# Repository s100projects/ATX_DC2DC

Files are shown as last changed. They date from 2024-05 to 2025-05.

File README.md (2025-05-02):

# ATX_DC2DC 
## Project Purpose and Goal ##
<b>The ATX DC2DC power supply board uses a 550W or greater ATX PC power supply (PSU) to generate common S-100 Bus voltages for S-100 computers and floppy disk drives.</b>

<b>Table of Contents:</b>
- [Project Overview](#project-overview)
  - [ATX DC2DC Board Image](#atx-dc2dc-board-image)
  - [ATX DC2DC Board Features](#atx-dc2dc-board-features)
  - [S-100 Voltage Outputs and Currents](#s-100-voltage-outputs-and-currents)
  - [ATX PSU Requirements](#atx-psu-requirements)
  - [ATX DC2DC Jumper Assignments](#atx-dc2dc-jumper-assignments)
- [ATX DC2DC Thermal and Current Limits](#atx-dc2dc-thermal-and-current-limits)
  - [7.5V or 8V Current and Thermal Limits](#7.5v-or-8v-current-and-thermal-limits)
  - [24V Current and Thermal Limits](#24v-current-and-thermal-limits)
  - [16V Current and Thermal Limits](#16v-current-and-thermal-limits)
  - [Fan Requirements above 70% Loading](#fan-requirements-above-70%-loading)
- [Installation and Wiring Requirements](#installation-and-wiring-requirements)
  - [ATX DC2DC Dimensions and Connector Locations](#atx-dc2dc-dimensions-and-connector-locations)
  - [Connector Pinout Tables](#connector-pinout-tables)
    - [J1: ATX Main Power Connector](#j1-atx-main-power-connector)
    - [J3: ATX CPU Power Connector](#j3-atx-cpu-power-connector)
    - [J5: ATX PCIE Power Connector](#j5-atx-pcie-power-connector)
    - [J13-14: 8in. Disk DC Power Connectors](#j13-14-8in-disk-dc-power-connectors)
    - [J15: S-100 Bus Power Output Connector](#j15-s-100-bus-power-output-connector)
    - [J16: Voltage/Current Monitor Connector](#j16-voltagecurrent-monitor-connector)
    - [J17: Control/Status Connector](#j17-controlstatus-connector)
    - [J22: FAN Control Connector](#j22-fan-control-connector)
    - [J23-26: PC FAN Connectors](#j23-26-pc-fan-connectors)

## Project Overview ##

The ATX DC2DC board was implemented as a 5.5" x 3.4" PCB to match the side profile of the common ATX power supply case to allow for using a 3D printed base-plate with double-sided tape to mount the ATX DCDC to the ATX PSU.

### ATX DC2DC Board Image ###

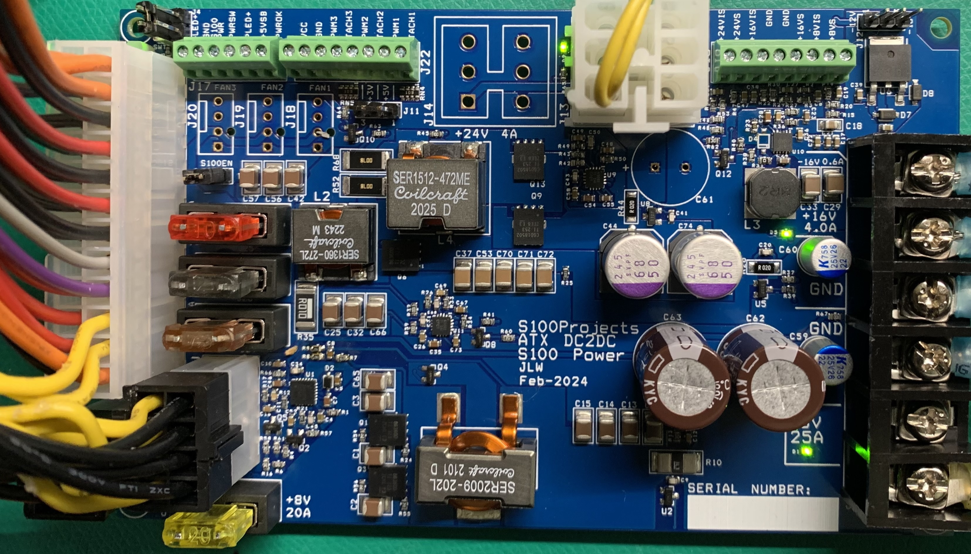
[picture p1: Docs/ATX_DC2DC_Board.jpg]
picture alt T35_FPGA_Module


### ATX DC2DC Board Features ###
The ATX DC2DC Board replaces several discrete power supply setups using efficient switching regulator power sections (+7.5V or +8V, +/-16V, and +24) and a readily available ATX PSU of 550 Watts or greater (See <b>ATX PSU Requirements</b> below).

<b>Current Features:</b>
  - Uses ATX Power Connectors (24-pin, 8-pin and 6-pin)
  - Supports common S-100 Voltages
  - Supports common 8" Disk Drive Voltages
  - Three 3/4-pin 12V PC Fan Connectors (with Tach and PWM off-board connections)
  - Microprocessor level (0 to 3.3V) voltage and current monitors for S-100 voltages
  - Over-current and over-temperature shutdown protection
  - Input fuses for each power supply section

### S-100 Voltage Outputs and Currents ###

  | <b>S-100 Output</b>   | <b>Function</b>                       | <b>Default Fuse Values</b>      |
  |----------------|--------------------------------|-----------------------|
  | <b>+7.5V</b> @ 25.0A   | Main Logic Supply on S-100 Bus | <b>~16.4A</b> (20.0A Fuse)   |
  |     - or -          |                                |                              |
  | <b>+8.0V</b> @ 22.0A   | Main Logic Supply on S-100 Bus | <b>~16.4A</b> (20.0A Fuse)   |
  | <b>+16V</b> @ 4.0A     | Logic/Shifter/Analog Supply    | <b>~5.7A</b>   (7.5A Fuse)   |
  | <b>-16V</b> @ 0.5A     | Level Shifter/Analog Supply    | <b>~0.8A</b>   (2.0A Fuse)   |
  | <b>+24V</b> @ 4.0A     | 8in. Floppy Drive Supply       | <b>~8.8A</b>  (10.0A Fuse)   |
  | <b>-5V</b> @ 0.3/0.5A\* | 8in. Floppy Drive Supply       | <b>Int. Limited to 0.5A</b>  |
  | <b>+5V</b> \*\*          | 8in. Floppy Drive Supply       | <b>Limited by ATX PSU</b>    |

\* = 0.3A when -5V Regulator is supplied by -16V Switcher.  
\* = 0.5A when -5V Regulator is supplied by -12V from ATX PSU.  
\*\* = Limited by ATX PSU.

Since not all ATX PSU's supply a -12V voltage (used by the on-board -5V regulator for the 8-in. Floppy Drive Power Connectors), a jumper is provided to optionally supply this -5V regulator from the -16V supply that the ATX DC2DC generates.  Due to dissipation reasons, the current output of the -5V regulator is reduced to 0.3A when driven from the -16V supply.

### ATX PSU Requirements ###

The main determination of which ATX PSU are acceptable are driven by the 12V load of the ATX DC2DC itself and the maximum load present on its outputs.  If you will be using the ATX DC2DC Board at its maximum load limits (as shown above) then you will need at least <b>32 amps</b> at 12V.  However, additional 12V loads such as Fans, Hard-Drives, LEDs, et cetera, will raise this requirement.  As a general rule, it is advised to add 5% or 10% margin to the current requirements to account for unanticipated loads or losses. 

### ATX DC2DC Jumper Assignments ###

  | <b>Jumper Number</b>  | <b>Description</b>                    | <b>Default Setting/Voltages</b> |
  |----------------|--------------------------------|-----------------------|
  | <b>J1  - 24-Pins</b>  | ATX Main Power Cable           | +3.3V, +5.0V, +12V, -12V                |
  | <b>J2  - 2-Pins</b>    | ATX Power Switch Connection    | Short pins for ATX PSU On               |
  | <b>J3  - 8-Pins</b>    | ATX 12V CPU Power Cable        | +12V when ATX PSU is On                 |
  | <b>J4  - 3-Pins</b>    | ATX Power LED Connection       | Pin 1 - Anode, 3 - Cathode              |
  | <b>J5  - 6-Pins</b>    | ATX 12V PCIE Power Cable       | +12V when ATX PSU is On                 |
  | <b>J10 - 2-Pins</b>    | S-100 Power Enable\*            | Power Enabled when shorted              |
  | <b>J11 - 3-Pins</b>    | Fan VCC Select - (for PWM)     | 1-2=5V, 2-3=3.3V                        |
  | <b>J12 - 3-Pins</b>    | -5V In Select (-12/-16)        | 1-2=-12V, 2-3=-16V                      |
  | <b>J13/14 - 6-Pins</b> | 8-in Drive Power Sockets       | 2/3/6=GND, 1=+24V, 4=-5V, 5=5V          |
  | <b>J15 - 6-Pins</b>    | S-100 Bus Voltage Outputs      | 1/2=+7.5V, 3/4=GND, 5=+16V, -16V        |
  | <b>J16 - 8-Pins</b>    | Voltage/Current Monitor Output | (See V/I Monitor Pinout)                |
  | <b>J17 - 6-Pins</b>    | Control/Status Port            | (See Control/Status Port Pinout)        |
  | <b>J18-20 - 4-Pins</b> | PC Fan Connections             | 1=GND, 2=+12V, 3=TACH, 4=PWM            |
  | <b>J22 - 8-Pins</b>    | Fan Control Connector          | (See Fan Control Connector Pinout)      |
  | <b>J23-26 - 2-Pins</b> | Power Supply Fuses             | J23=+7.5V, J24=+16V, J25=+24V, J26=-16V |
  
## ATX DC2DC Thermal and Current Limits ##

As shown above, the ATX DC2DC S-100 Power Supply Board can provide >350W of S-100 voltages, typically at 95%+ efficiency.

Even at those efficiency levels though, you will still have close to 18-watts of heat dissipation at full load.  The board can dissipate, with natural convection (under 25C ambient conditions), up to approximately 12-watts of heat safely without the need of a fan in a typical 25C environment. (Note - most of this heat is generated by the 7.5V/8.0V regulator section of the board).  Above that limit, a 60mm or larger fan is required to avoid thermal shutdowns and possible damage to the ATX DC2DC board.

As an example, the following characterization image was taken of the ATX DC2DC's 7.5V output at 25A loading with a resistor "Load Box".

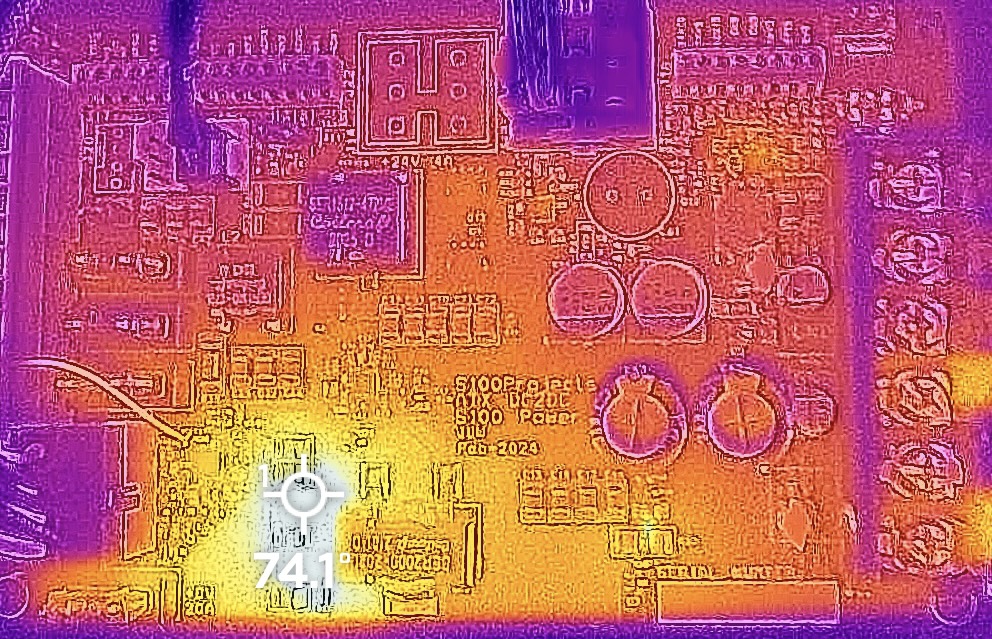
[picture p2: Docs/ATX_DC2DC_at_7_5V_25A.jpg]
picture alt ATX_DC2DC_FULL_LOAD


In the above image the white region (at 74.1C) is the heat generated by the 7.5V/8V Switching Regulator MOSFETs when supplying 25 amps when forced-air cooled with a 60mm PC fan (which is driven off of the on-board PC fan connectors).  74.1C represents a die temperature of ~94.1C.  Since the MOSFET absolute maximum temperature is 150C, this represents 56C of headroom, or up to 76C ambient temperature.  I have derated this slightly to an operational range of 0C to 70C for most uses of the board.

Note: The two yellow temperatures areas to the lower right of the image are the +7.5V and Ground connections to the resistor load box and represent the heat generated by the wire resistance when conducting 25 amps of current.

This test was made with a resistor load box to dissipate the 187-watts of heat generated.  For the curious, here is a picture of the load box when under full load.  I have since added a fan to the load box for longevity reasons since 150C is at the limit for the resistors used.

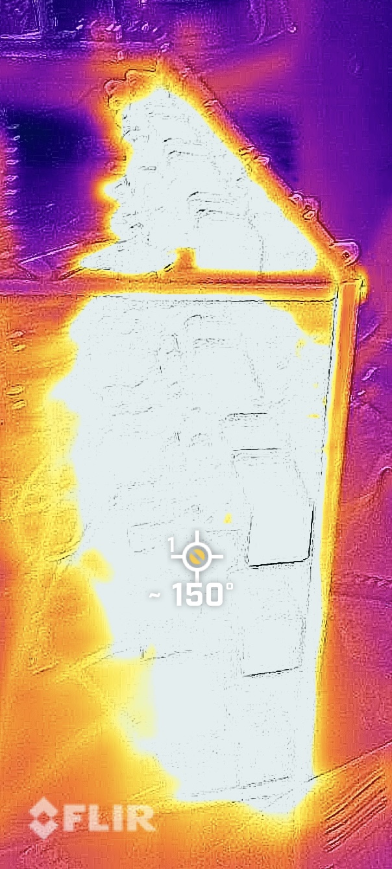
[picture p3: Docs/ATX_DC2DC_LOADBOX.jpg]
picture alt ATX_DC2DC_LOADBOX


### 7.5V or 8V Current and Thermal Limits ###

Due to the thermal constraints shown above, the current limits for the 7.5V and 8V versions of the ATX DC2DC are catagorized into four catagories according to these operational limits.  The categories are 7.5V vs 8V and Fanless vs Fan cooling.

  | <b>Operational Mode</b> | <b>Current Limit</b> | 
  |------------------|-----------------|
  | <b>7.5V - No Fan</b>    | 17 Amps       |
  | <b>8.0V - No Fan</b>    | 15 Amps       |
  | <b>7.5V - 60mm Fan</b>  | 25 Amps       |
  | <b>8.0V - 60mm Fan</b>  | 22 Amps       |

  These are characterized limits, but convection currents, airflow patterns, and venting efficiencies within different enclosures can vary wildly, so please error on the side of caution.  More airflow is generally better. 

### 24V Current and Thermal Limits ###

The 24V 8" drive supply section behaves similarly to that of the 7.5v/8V section.  Above 2.7-amps of continuous loading, a fan is required.  Startup currents are generally not a factor in the thermal limits described here.

### 16V Current and Thermal Limits ###

The 16V section takes advantage of a lower voltage and more efficient MOSFET than can be used in the 24V section (primarily because the higher switching voltages in the 24V section did not allow for using the lower voltage MOSTFET).

However, since the 16V section does use the more efficient MOSFET, it does not require a fan to achieve its full loading of 4-amps.  A fan may still be required depending on the loading for the other output voltages.

### Fan Requirements above 70% Loading ###

Regardless of the individual current loadings, whenever the output currents are 70% or higher of the total current limits, a fan should be used.

## Installation and Wiring Requirements ##

For the lowest voltage drop (cable loss) of the power cables to the S-100 Bus and 8in. Drives, please follow the following chart for wire sizes according to load current:

  | <b>Output @ Amps</b>   | <b>Wire Type</b>                       | <b>Wire Gauge</b>      |
  |----------------|--------------------------------|-----------------------|
  | <b>+7.5V</b> @ 25.0A (J15)    | 1-Wire 7-strand or higher copper | <b>10-Guage</b>      |
  | <b>+7.5V</b> @ 25.0A (J15)    | 2-Wire 7-strand or higher copper | <b>18-Guage</b>      |
  | <b>+8.0V</b> @ 25.0A (J15)    | 1-Wire 7-strand or higher copper | <b>10-Guage</b>      |
  | <b>+8.0V</b> @ 22.0A (J15)    | 2-Wire 7-strand or higher copper | <b>18-Guage</b>      |
  | <b>+16V</b>  @ 4.0A  (J15)    | 1-Wire 7-strand or higher copper | <b>20 or 22-Guage</b>|
  | <b>-16V</b>  @ 0.5A  (J15)    | 1-Wire 7-strand or higher copper | <b>20 or 22-Guage</b>|
  | <b>+24V</b>  @ 4.0A  (J13/14) | 1-Wire 7-strand or higher copper | <b>20 or 22-Guage</b>|
  | <b>-5V</b>   @ 0.5A  (J13/14) | 1-Wire 7-strand or higher copper | <b>20 or 22-Guage</b>|
  | <b>+5V</b>   @ 4.0A  (J13/14) | 1-Wire 7-strand or higher copper | <b>20 or 22-Guage</b>|

NOTE: On PVC vs THHN - THHN (Teflon Coated Wire) does not increase the current carrying capability of a wire.  It does increase the temperature rating before failure.  Simply put, it can dissipate more heat so a smaller wire can be used, but it comes at the cost of a larger voltage drop and more losses in the cable.  However, THHN can be used at the above wire guage limits as it offers better abrasion resistance, heat tolerance, and is easier to pull through tight spaces due to its Teflon coating.

### ATX DC2DC Dimensions and Connector Locations ###

The following diagram shows the dimensions and the mounting holes and connector locations:

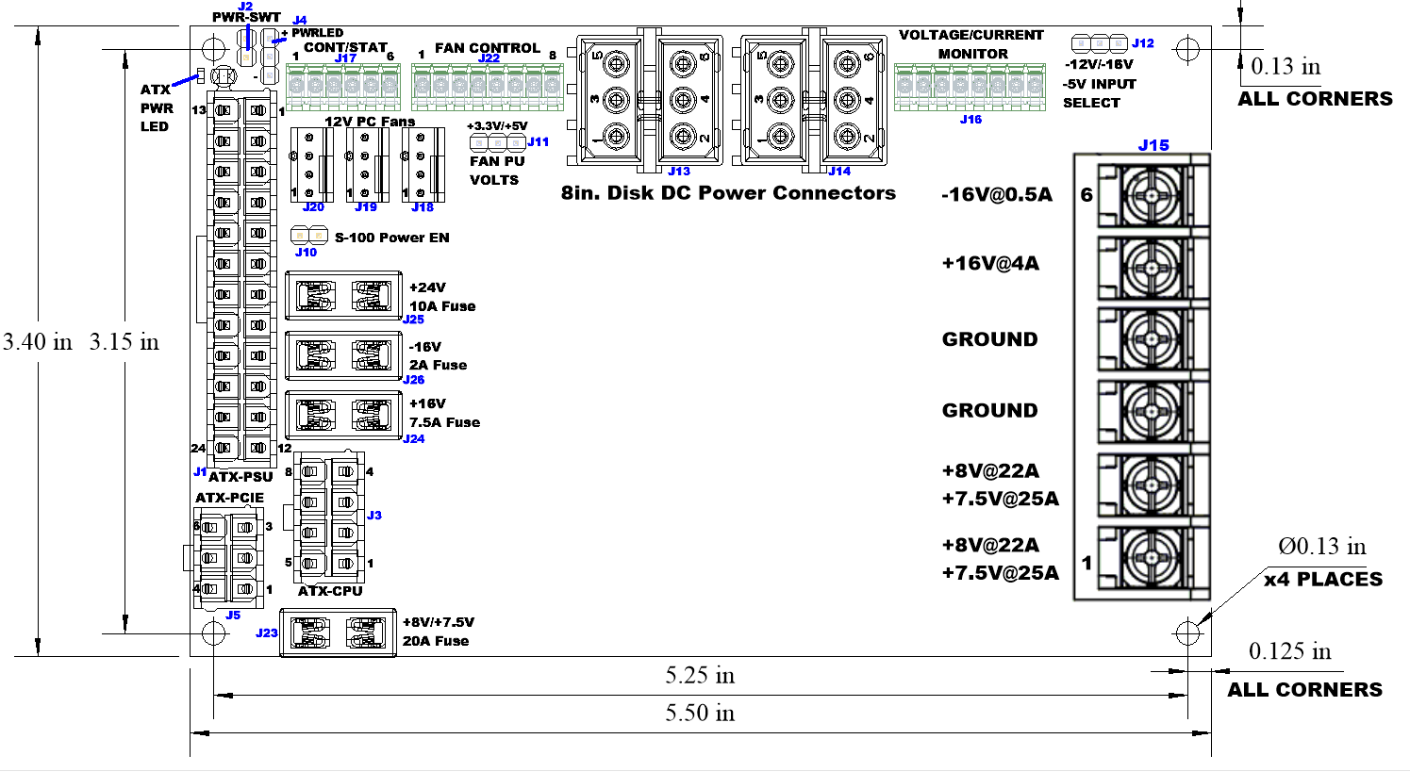
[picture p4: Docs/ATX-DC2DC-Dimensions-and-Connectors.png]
picture alt ATX_DC2DC_DIMENSIONS


It is recommended that the ATX DC2DC Board be mounted on a panel with standoffs of at least 0.25" to allow for airflow underneath the PCB for cooling at high loads.

### Connector Pinout Tables ###

#### J1: ATX Main Power Connector ####

  | <b>Pin Number </b>   | <b>ATX Function</b>                       | <b>ATX DC2DC Use</b>      |
  |----------------|--------------------------------|-----------------------|
  | <b>1</b>     | +3.3V | <b>Bias Voltage for Fans and LEDs</b>      |
  | <b>2</b>     | +3.3V | <b>Bias Voltage for Fans and LEDs</b>      |
  | <b>3</b>     | Ground | <b>Ground for Board</b>|
  | <b>4</b>     | +5.0V | <b>Bias Voltage and LED Supply</b>|
  | <b>5</b>     | Ground | <b>Ground for Board</b>|
  | <b>6</b>     | +5.0V | <b>Bias Voltage and LED Supply</b>|
  | <b>7</b>     | Ground | <b>Ground for Board</b>|
  | <b>8</b>     | Power OK | <b>Used to enable on board regulators</b>|
  | <b>9</b>     | +5V Standby | <b>Connected to PWREN Pin 2 for external use</b>|
  | <b>10</b>    | +12.0V | <b>Used as main supply for on-board regulators</b>|
  | <b>11</b>    | +12.0V | <b>Used as main supply for on-board regulators</b>|
  | <b>12</b>    | +3.3V | <b>Bias Voltage for Fans and LEDs</b>      |
  | <b>13</b>    | +3.3V | <b>Bias Voltage for Fans and LEDs</b>      |
  | <b>14</b>    | -12V (if supported) | <b>Input to -5V Regulator</b>      |
  | <b>15</b>    | Ground | <b>Ground for Board</b>|
  | <b>16</b>    | Power Switch Input | <b>Connected to PWREN Pin 4</b>|
  | <b>17</b>    | Ground | <b>Ground for Board</b>|
  | <b>18</b>    | Ground | <b>Ground for Board</b>|
  | <b>19</b>    | Ground | <b>Ground for Board</b>|
  | <b>20</b>    | No Connect | <b>Not Used</b>|
  | <b>21</b>    | +5.0V | <b>Bias Voltage and LED Supply</b>|
  | <b>22</b>    | +5.0V | <b>Bias Voltage and LED Supply</b>|
  | <b>23</b>    | +5.0V | <b>Bias Voltage and LED Supply</b>|
  | <b>24</b>    | Ground | <b>Ground for Board</b>|

#### J3: ATX CPU Power Connector ####

  | <b>Pin Number </b>   | <b>ATX Function</b>                       | <b>ATX DC2DC Use</b>      |
  |----------------|--------------------------------|-----------------------|
  | <b>1</b>     | Ground | <b>Ground for Board</b>|
  | <b>2</b>     | Ground | <b>Ground for Board</b>|
  | <b>3</b>     | Ground | <b>Ground for Board</b>|
  | <b>4</b>     | Ground | <b>Ground for Board</b>|
  | <b>5</b>     | +12.0V | <b>Used as main supply for on-board regulators</b>|
  | <b>6</b>     | +12.0V | <b>Used as main supply for on-board regulators</b>|
  | <b>7</b>     | +12.0V | <b>Used as main supply for on-board regulators</b>|
  | <b>8</b>     | +12.0V | <b>Used as main supply for on-board regulators</b>|

#### J5: ATX PCIE Power Connector ####

  | <b>Pin Number </b>   | <b>ATX Function</b>                       | <b>ATX DC2DC Use</b>      |
  |----------------|--------------------------------|-----------------------|
  | <b>1</b>     | +12.0V | <b>Used as main supply for on-board regulators</b>|
  | <b>2</b>     | +12.0V | <b>Used as main supply for on-board regulators</b>|
  | <b>3</b>     | +12.0V | <b>Used as main supply for on-board regulators</b>|
  | <b>4</b>     | Ground | <b>Ground for Board</b>|
  | <b>5</b>     | Ground | <b>Ground for Board</b>|
  | <b>6</b>     | Ground | <b>Ground for Board</b>|

#### J13-14: 8in. Disk DC Power Connectors ####

  | <b>Pin Number </b>   | <b>ATX DC2DC Function</b>    | <b>ATX DC2DC Use</b>      |
  |----------------|--------------------------------|-----------------------|
  | <b>1</b>     | +24V   | <b>+24V @ 4A supply for Disk Drives</b>|
  | <b>2</b>     | Ground | <b>Ground for Disk Drives</b>|
  | <b>3</b>     | Ground | <b>Ground for Disk Drives</b>|
  | <b>4</b>     | -5V    | <b>-5V supply | <b>-5V @ 0.3A/0.5A for Disk Drives\*</b>|
  | <b>5</b>     | +5V    | <b>+5V supply for Disk Drives (supplied by ATX +5V)</b>|
  | <b>6</b>     | Ground | <b>Ground for Disk Drives</b>|

\* = Supplied by ATX -12V (@ 0.5A) or -16V S-100 Supply (@ 0.3A)

#### J15: S-100 Bus Power Output Connector ####

  | <b>Pin Number </b>   | <b>ATX DC2DC Function</b>    | <b>ATX DC2DC Use</b>      |
  |----------------|--------------------------------|-----------------------|
  | <b>1</b>     | +7.5V/+8V | <b>+7.5V/+8V up to 25A/22A for S-100 Bus</b>|
  | <b>2</b>     | +7.5V/+8V | <b>+7.5V/+8V up to 25A/22A for S-100 Bus</b>|
  | <b>3</b>     | Ground | <b>Ground return for S-100 Bus</b>|
  | <b>4</b>     | Ground | <b>Ground return for S-100 Bus</b>|
  | <b>5</b>     | +16V   | <b>+16V up to 4A for S-100 Bus</b>|
  | <b>6</b>     | -16V   | <b>-16V up to 0.5A for S-100 Bus</b>|

#### J16: Voltage/Current Monitor Connector ####

The Voltage/Current Monitor signals allow for the use of a micro-controller or programmable Panel Meter to monitor and display the S-100 and 8-inch Drive power supply voltages and curents.

  | <b>Pin Number </b>   | <b>ATX DC2DC Function</b>         | <b>ATX DC2DC Use</b>      |
  |----------------|--------------------------------|-----------------------|
  | <b>1</b>     | 8VS: +7.5V/8V Voltage Sense  | <b>8.0V = 2.0V +/-5%</b>|
  | <b>2</b>     | 8VIS: +7.5V/8V Current Sense   | <b>25A = 2.5V +/-5%</b>|
  | <b>3</b>     | 16VS: +16V Voltage Sense  | <b>15.0V = 4.0V +/-5%</b>|
  | <b>4</b>     | Ground | <b>Ground for Signals</b>|
  | <b>5</b>     | Ground | <b>Ground for Signals</b>|
  | <b>6</b>     | 16VIS: +16V Current Sense  | <b>2.5A = 1.24V +/-10%</b>|
  | <b>7</b>     | 24VS: +24V Voltage Sense   | <b>24.0V = 2.4V +/-5%</b>|
  | <b>8</b>     | 24VIS: +24V Current Sense  | <b>2.5A = 1.24V +/-10%</b>|

#### J17: Control/Status Connector ####

  | <b>Pin Number </b>   | <b>ATX DC2DC Function</b>                       | <b>ATX DC2DC Use</b>      |
  |----------------|--------------------------------|-----------------------|
  | <b>1</b>     | PWR OK     | <b>Used to control regulator startup</b>|
  | <b>2</b>     | +5V Stndby | <b>Always on supply for expansion connections</b>|
  | <b>3</b>     | PWRLED     | <b>External Connection for Stand PC Power LED</b>|
  | <b>4</b>     | PWRSWT     | <b>Used to control ATX Power Supply: GND = ON</b>|
  | <b>5</b>     | S100EN     | <b>Enables S-100 Power Supplies when low (open only for testing purposes)\*</b>|
  | <b>6</b>     | Ground     | <b>Ground for Board</b>|

\* = The only supplies that go to 0 volts when S100EN is high or unconnected are the +7.5V/+8V and -16V supplies.  The +16V and +24V supplies will be passively supplied with +12V via MOSFET protection diodes.  If a true zero volts is required, the user will need to power down the ATX PSU via the PWRSWT input.

#### J22: FAN Control Connector ####

  | <b>Pin Number </b>   | <b>ATX DC2DC Function</b>                       | <b>ATX DC2DC Use</b>      |
  |----------------|--------------------------------|-----------------------|
  | <b>1</b>     | TACH1  | <b>Tach output from Fan-1</b>|
  | <b>2</b>     | PWM1   | <b>PWM Input for Fan-1 </b>|
  | <b>3</b>     | TACH2  | <b>Tach output from Fan-2</b>|
  | <b>4</b>     | PWM2   | <b>PWM Input for Fan-2</b>|
  | <b>5</b>     | TACH3  | <b>Tach output from Fan-3</b>|
  | <b>6</b>     | PWM3   | <b>PWM Input for Fan-3 </b>|
  | <b>7</b>     | Ground | <b>Ground for Signals</b>|
  | <b>8</b>     | +PUV   | <b>Pull Up Voltage for Fan Signals (3.3V/5V Selected by FAN PU Jumper)</b>|

#### J23-26: PC FAN Connectors ####

  | <b>Pin Number </b>   | <b>ATX DC2DC Function</b>                       | <b>ATX DC2DC Use</b>      |
  |----------------|--------------------------------|-----------------------|
  | <b>1</b>     | Ground | <b>Ground for Fans</b>|
  | <b>2</b>     | +12.0V | <b>+12V Supply to PC Fan</b>|
  | <b>3</b>     | TACH   | <b>Tach output from Fan</b>|
  | <b>4</b>     | PWM    | <b>PWM Input for Fan</b>|

n.b. - Pin 1 is at the bottom of the connector in the above diagram.

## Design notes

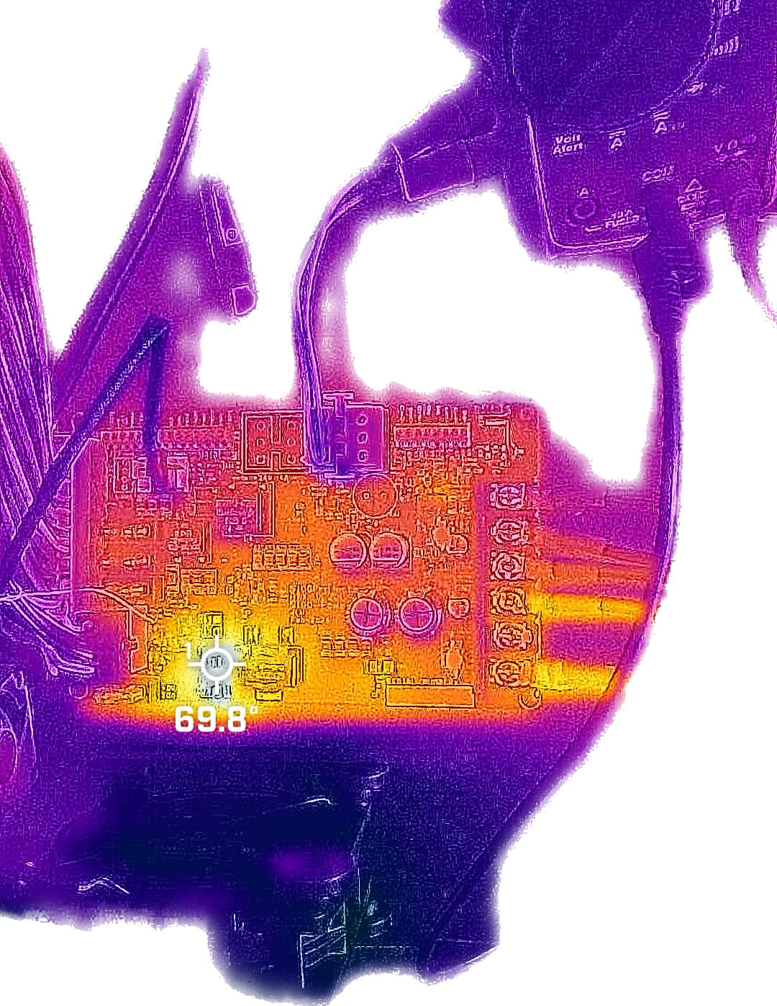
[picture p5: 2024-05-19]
Docs/Subject.png

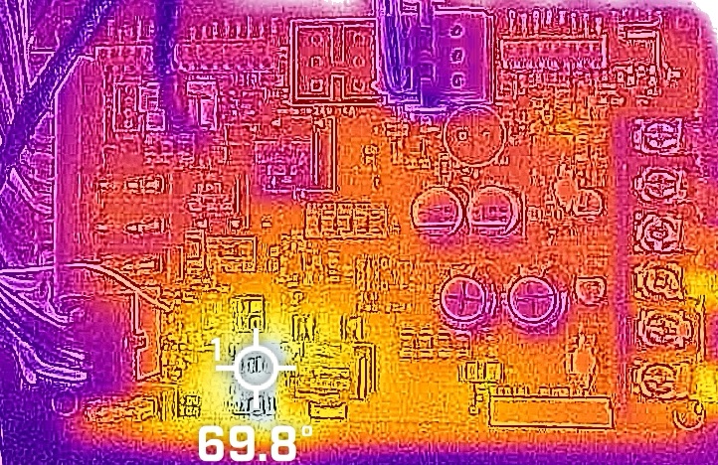
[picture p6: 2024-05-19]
Docs/ATX_DC2DC_Thermal.jpg

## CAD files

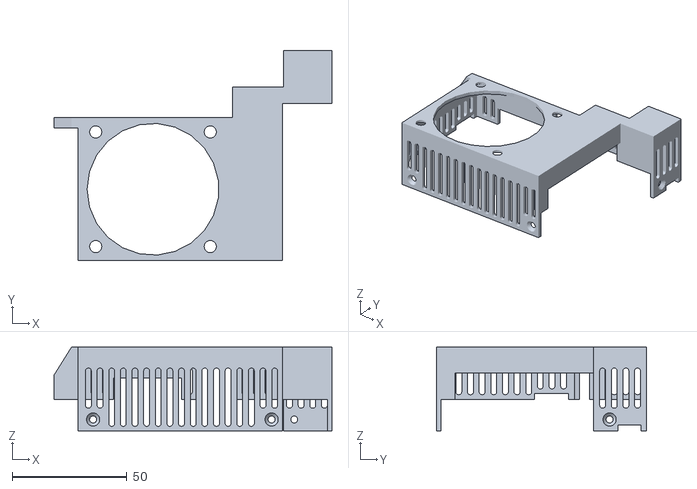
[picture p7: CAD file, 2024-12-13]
CAD/ATX_DC2DC_PSU_Cage_TopV2.stl
121.3 x 91.4 x 36.6

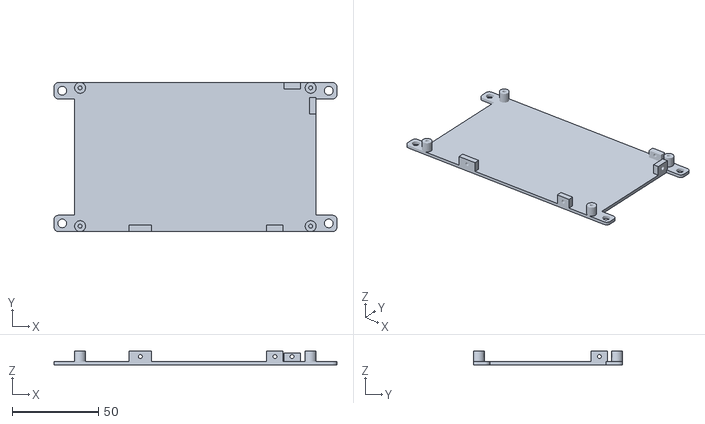
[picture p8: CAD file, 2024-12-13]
CAD/ATX_DC2DC_PSU_Base3.stl
163.7 x 86.4 x 8.38

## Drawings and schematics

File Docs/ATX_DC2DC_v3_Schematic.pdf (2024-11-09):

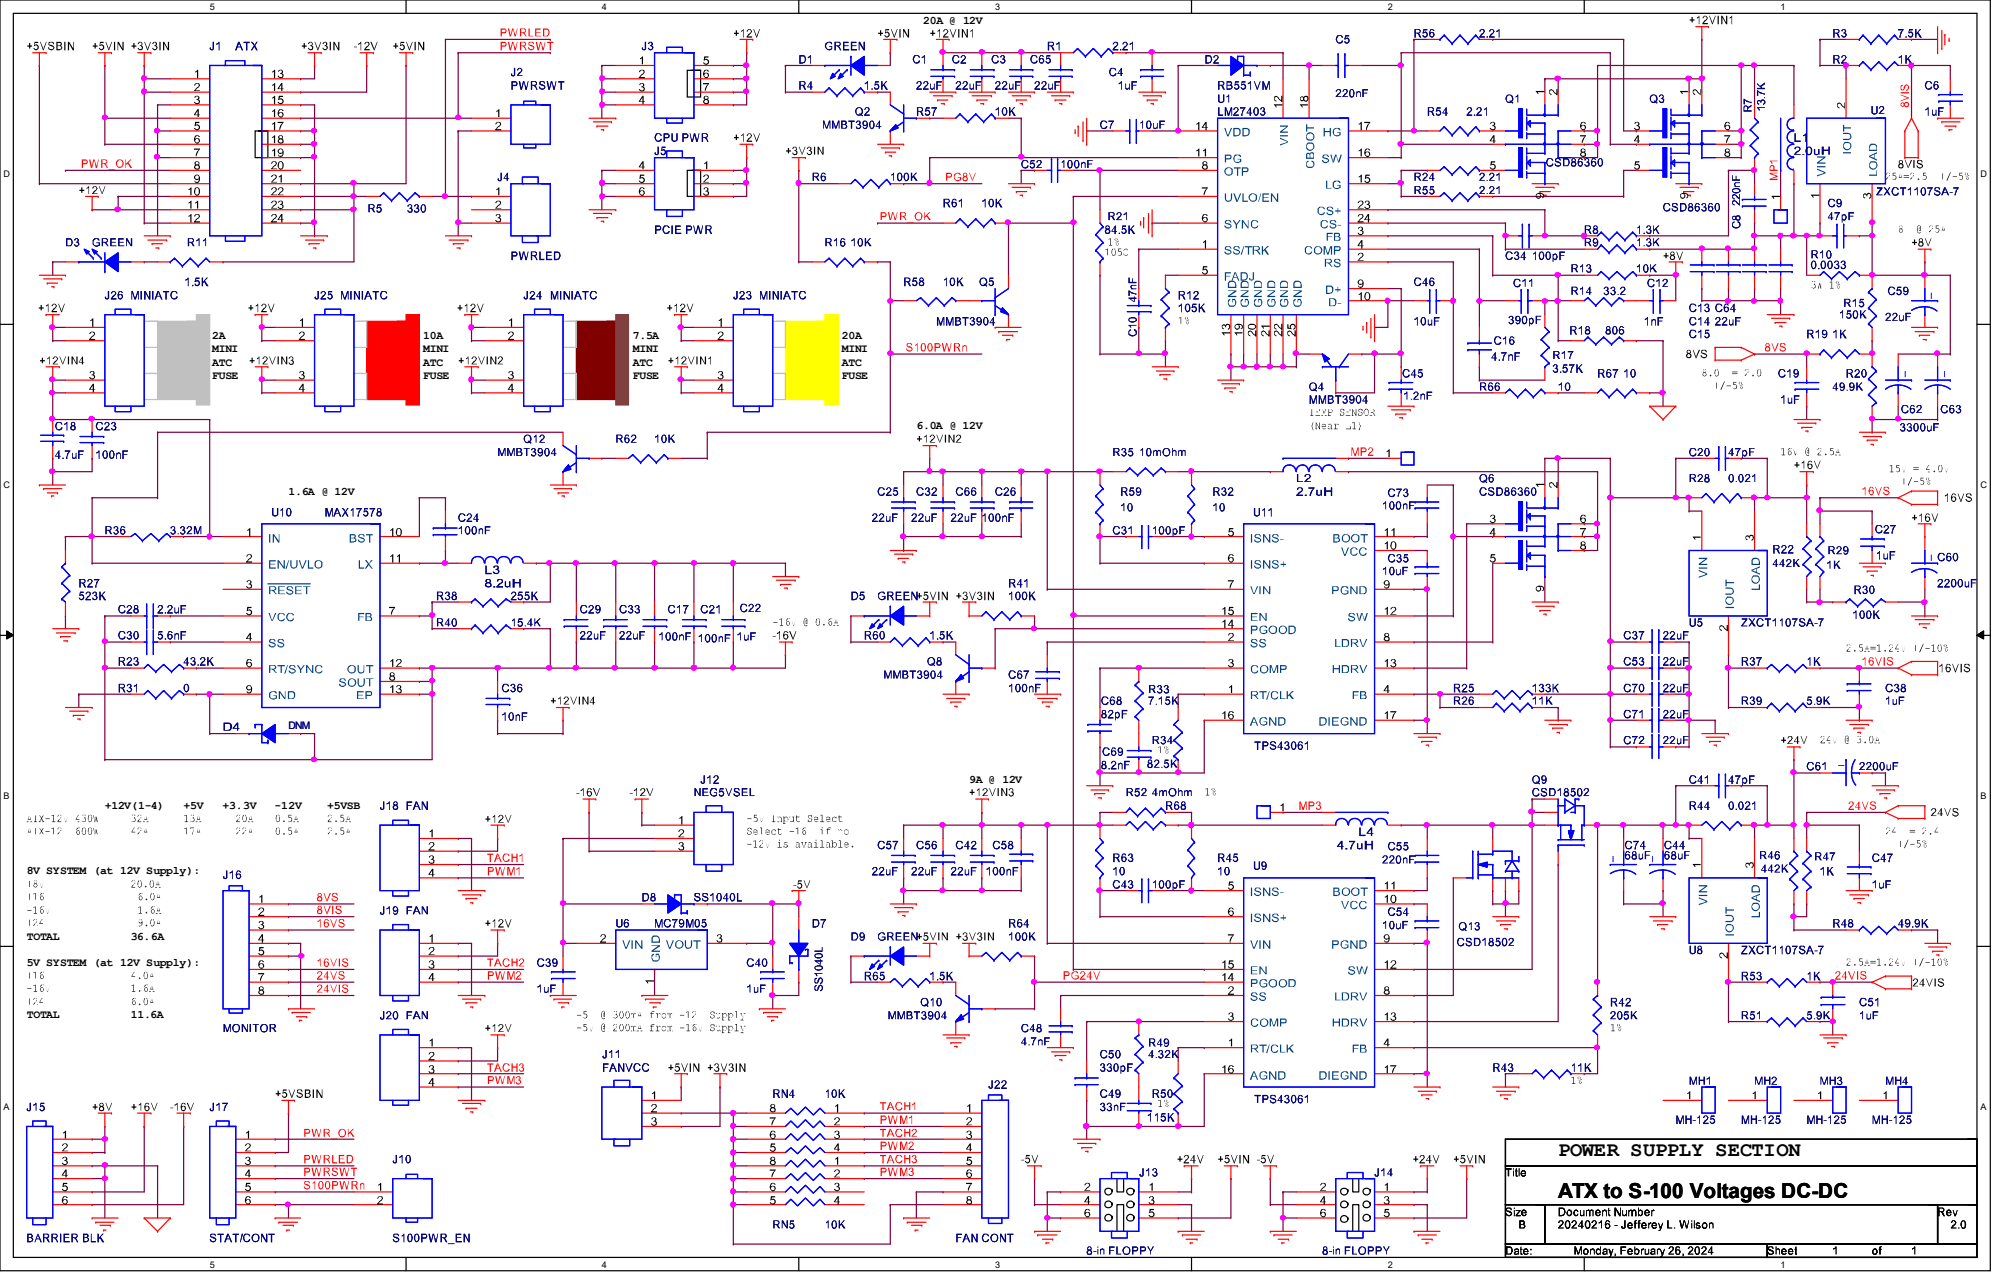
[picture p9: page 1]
+5VSB; TOTAL; 10A MINI ATC FUSE; 2A MINI ATC FUSE; 7.5A MINI ATC FUSE; 20A MINI ATC FUSE; DNM

8V SYSTEM (at 12V Supply):

5V SYSTEM (at 12V Supply):

POWER SUPPLY SECTION

ATX to S-100 Voltages DC-DC

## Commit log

2024-05-22 Updated Pinouts
    Updated Pinouts and added Board Dimension Diagram
2024-11-09 Create ATX_DC2DC_v3_Schematic.pdf
    Added Schematic.
2024-12-13 Added ATC DC2DC Case CAD Files
    [ATX_DC2DC_PSU_Base3.stl, ATX_DC2DC_PSU_Cage_TopV2.stl]
